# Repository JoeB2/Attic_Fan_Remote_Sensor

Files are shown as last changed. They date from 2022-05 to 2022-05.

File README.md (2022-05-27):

"# attic_fan_remote_sensor" 
Deep Sleep for "deepSleep_us" Value provided by Attic Fan Controller via ESPNOW

On Wake up this unit reads values from a BME280 and its internal VCC and then sends a, 32bytes (JSON string), using ESPNOW
to the Attic Fan Controller of temp/humid/press/vcc.  The Attic Fan Controller updates its struct with the remote values and sends
a JSON string to the Web Page it hosts using WebSockets.  This ESP01 supports ESPNOW only - no WiFi.

The first Remote Sensor iteration of this remote sensor is using two 18650 2300 mah LIPO Cells.

All LEDs on the ESP01 have been removed.
This ESP01 uses 18 ua (18 Micro Amp) in deep sleep and an average of 66 ma for 212 ms during its awake & transmit period.
With a 2 minute deep sleep cycle we could see extended periods of battery life perhaps several years.  (TBD)

If the Attic Fan Controller unit sends an updated sleep_us value this ESP01 power consuption jumps to 385ma during the communication rcx cycle ~45ms. yikes!

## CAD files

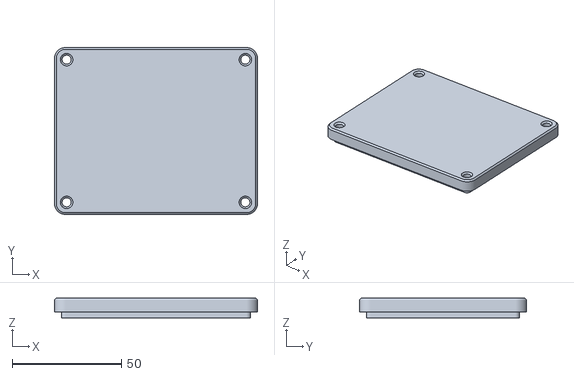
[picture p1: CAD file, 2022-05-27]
box/Lid-AtticFanController.stl
92.8 x 76.3 x 9.05

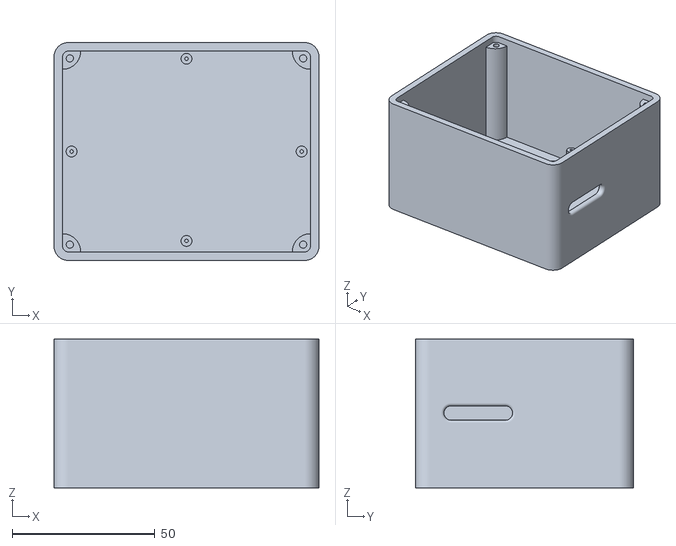
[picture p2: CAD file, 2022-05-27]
box/Box-AtticFanController.stl
92.8 x 76.3 x 52.1

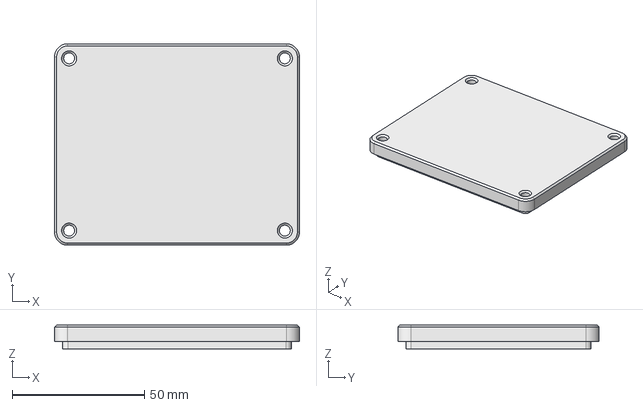
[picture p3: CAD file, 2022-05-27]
box/electonics_box.FCStd
92.8 x 76.3 x 9.05 mm

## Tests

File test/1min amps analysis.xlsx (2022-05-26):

ms | uA
0 | 17.79 | One minute test run. Deep sleep 3 seconds after ESPNOW send of 32 bytes.C45
1 | 17.959 |  | Avgerage ua |  | Period
2 | 17.666 |  | 66042.29058 |  | 212ms
3 | 17.818
4 | 17.728
5 | 17.581
6 | 17.747
7 | 17.763
8 | 17.789
9 | 17.78
10 | 17.783
11 | 17.793
12 | 17.789
13 | 17.79
14 | 17.777
15 | 17.759
16 | 17.786
17 | 17.83
18 | 17.871
19 | 17.838
20 | 17.814
21 | 17.797
22 | 17.805
23 | 17.795
24 | 17.8 |  | avg 2737ua | 6043ms
25 | 17.796
26 | 17.781
27 | 17.751
28 | 17.773
29 | 17.773
30 | 17.764
31 | 17.76
32 | 17.759
33 | 17.755
34 | 17.786
35 | 17.76
36 | 17.76
37 | 17.743
38 | 17.779
39 | 17.802
40 | 17.787
41 | 17.778
42 | 17.761
43 | 17.775
44 | 17.778
45 | 17.743
46 | 17.746
47 | 17.719
48 | 17.784
49 | 17.778
50 | 17.776
51 | 17.767
52 | 17.753
53 | 17.789
54 | 17.795
55 | 17.76
56 | 17.75
57 | 17.741
58 | 17.779
59 | 17.814
60 | 17.774
61 | 17.787
62 | 17.732
63 | 17.787
64 | 17.776
65 | 17.755
66 | 17.78
67 | 17.714
68 | 17.773
69 | 17.796
70 | 17.771
71 | 17.788
72 | 17.734
73 | 17.816
74 | 17.828
75 | 17.837
76 | 17.845
77 | 17.747
78 | 17.806
79 | 17.808
80 | 17.777
81 | 17.764
82 | 17.733
83 | 17.79
84 | 17.799
85 | 17.795
86 | 17.831
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

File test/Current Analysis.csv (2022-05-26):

ms | uA
0 | 18
1 | 18
2 | 18
3 | 18
4 | 18
5 | 18
6 | 18
7 | 18
8 | 18
9 | 18
10 | 18
11 | 18
12 | 18
13 | 18
14 | 18
15 | 18
16 | 18
17 | 18
18 | 18
19 | 18
20 | 18
21 | 18
22 | 18
23 | 18
24 | 18
25 | 18
26 | 18
27 | 18
28 | 18
29 | 18
30 | 18
31 | 18
32 | 18
33 | 18
34 | 18
35 | 18
36 | 18
37 | 18
38 | 18
39 | 18
40 | 18
41 | 18
42 | 18
43 | 18
44 | 18
45 | 18
46 | 18
47 | 18
48 | 18
49 | 18
50 | 18
51 | 18
52 | 18
53 | 18
54 | 18
55 | 18
56 | 18
57 | 18
58 | 18
59 | 18
60 | 18
61 | 18
62 | 18
63 | 18
64 | 18
65 | 18
66 | 18
67 | 18
68 | 18
69 | 18
70 | 18
71 | 18
72 | 18
73 | 18
74 | 18
75 | 18
76 | 18
77 | 18
78 | 18
79 | 18
80 | 18
81 | 18
82 | 18
83 | 18
84 | 18
85 | 18
86 | 18
87 | 18
88 | 18
89 | 18
90 | 18
91 | 18
92 | 18
93 | 18
94 | 18
95 | 18
96 | 18
97 | 18
98 | 18
99 | 18
100 | 18
101 | 18
102 | 18
103 | 18
104 | 18
105 | 18
106 | 18
107 | 18
108 | 18
109 | 18
110 | 18
111 | 18
112 | 18
113 | 18
114 | 18
115 | 18
116 | 18
117 | 18
118 | 18
119 | 18
120 | 18
121 | 18
122 | 18
123 | 18
124 | 18
125 | 18
126 | 18
127 | 18
128 | 18
129 | 18
130 | 18
131 | 18
132 | 18
133 | 18
134 | 18
135 | 18
136 | 18
137 | 18
138 | 18
139 | 18
140 | 18
141 | 18
142 | 18
143 | 18
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

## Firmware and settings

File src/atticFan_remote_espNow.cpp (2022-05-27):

#include <Arduino.h>
/*
      Remote: ESPNOW, DS3231 - Send outside temp & pressure inch of Hg
      1) Remote Sensor:
            Use BME280 sensor, store sensor data in a struct "cond" conditions
            Use espnow: broadcast struct "cond" at sleep_us interval (user adjustable)
            attic esp returns the struct with the sleep_us
            and if the current sleep_us is different we update cond.sleepTime & RTC memory.
            We wait for the response from the "Attic Controller" if after 7 seconds no response:
            this mcu initiates deep sleep

      2) uncomment //#define dbg enables Serial prints at several key locations in the code including the MAC

      3)    esp01 for the remote MCU: requires solder a connection from GPIO16 to RST.
            deepSleep wakes up the MCU by output of signal at GPIO16.
      
      NOTE:
            the attic sensor/controller esp's now_Msg struct must have the exact same definition for the cond struct

  int(4), uint(4), uint32(4), long(4), uLong(4), uLongLong(8), short(2), ushort(2), float(4), double(8)
*/
// extern "C" {
//   #include "user_interface.h" // 
// }

//#define dbg
#ifdef dbg
  u32 ms=millis();
  #define trace Serial.printf("%i %lums, ", __LINE__, millis()-ms);ms=millis(); Serial.flush();
#else
  #define trace ;
#endif

#include <espnow.h>
#include <ESP8266WiFi.h>
#include <EEPROM.h>

#include <Wire.h>  // loaded in TinyBME280.h - should be called: i2c.h or soft_i2c.h  imho

#define WiFiChannel 7

ADC_MODE(ADC_VCC);

//u8 attic_mac[6] = {0xFF,0xFF,0xFF,0xFF,0xFF,0xFF};// MAC: MultiCast"
//u8 attic_mac[6] = {0xE8,0xDB,0x84,0xA9,0x13,0x3A};   // latest ESP01
u8 attic_mac[6] = {0x5C,0xCF,0x7F,0xE1,0x9B,0x8B};   // D1 mini

u32 startMillis=millis();
u16 vcc_correct = -90; // vcc == voltage/1000  : We add correction and divide by 1000
u64 sleep_us = 4000002; // default to 4sec 4us
u8 *p = (u8*)&sleep_us;    // pointer to sleep_us to ease handle by byte

// BME280 Values & Variables
#define SDA 0
#define SCL 2
#define BME280address 0x76

/******  PROTOTYPES  *******/
void OnDataRecv(uint8_t * mac, uint8_t *incomingData, uint8_t len);
void OnDataSent(uint8_t *mac_addr, uint8_t sendStatus);

// BME280
void BME280setup();
void BME280sleep ();
int32_t BME280temperature();
uint32_t BME280pressure();
uint32_t BME280humidity();
uint8_t BME_ID();

typedef struct remote_Data{
  int temp;
  u32 press;
  u32 humid;
  u64 sleep_us = 4000000;
  u16 vcc;

  String toStr(){
    char c[120];
    int n = sprintf(c, "{\"temp\":%i,\"press\":%u,\"humid\",:%u,\"vcc:%hu,\"sleep_us\":%llu}"
      , temp, press, humid, vcc, sleep_us);
    c[n]=0;
    return String(c);
  }
}remote_data_t;
remote_data_t cond;

  void setup() {
    system_update_cpu_freq(SYS_CPU_160MHZ);
    system_deep_sleep_set_option (2);   // No RF cal on wake-up
    // 1: Vdd and TX power, 18 ms // 2: Vdd only, 2 ms // 3: Full cal, 200ms
    system_phy_set_powerup_option (2);
    system_phy_set_rfoption (2);
#ifdef dbg
    Serial.begin(74880);
    Serial.setTimeout(2000);
    while(!Serial){}
#endif
    EEPROM.begin(8);
    for(u8 i=0;i<8;i++)p[i] = EEPROM.read(i);
    EEPROM.end();
    cond.sleep_us = sleep_us;
trace;
    WiFi.setPhyMode(WIFI_PHY_MODE_11B);
    WiFi.setOutputPower(20.5);  // range: 0dbm - 20.5dbm; default 18.5
    WiFi.mode(WIFI_STA);
    WiFi.disconnect();
trace;
    esp_now_init();
    esp_now_register_send_cb(OnDataSent);
    esp_now_register_recv_cb(OnDataRecv);
    esp_now_set_self_role(ESP_NOW_ROLE_COMBO);
    esp_now_add_peer(attic_mac, ESP_NOW_ROLE_COMBO, WiFiChannel, NULL, 0);
trace;
    Wire.begin(SDA, SCL);
    BME280setup();
trace;
    // get the readings once, during startup (here!)
    cond.temp  = BME280temperature(); // .018 x temp +32  : done at index.html
    cond.press = BME280pressure();    // p x 0.00029529983071445 = in Hg  done int index.html
    cond.humid = BME280humidity();    // humidity / 100 done in index.html
    BME280sleep();
    cond.vcc   = ESP.getVcc() + vcc_correct; // below 3.0volts shutdown; battery needs to be charged
trace;
    esp_now_send(attic_mac, (u8*)&cond, sizeof(cond));
    delay(45); // takes 45-51ms to get here. timeout after ~100ms -> goto sleep
#ifdef dbg
    Serial.printf("\n%i %s %lu\n", __LINE__, __FUNCTION__, millis());Serial.flush();
    Serial.printf("%i %s %lums, ", __LINE__, cond.toStr().c_str(), millis());Serial.flush();
#endif
     ESP.deepSleepInstant(sleep_us, WAKE_RFCAL);
  }
  void loop(){}
  void OnDataRecv(uint8_t * mac, uint8_t *incomingData, uint8_t len){
trace;
    for(u8 i=0;i<len;i++)p[i] = incomingData[i];
trace;
    if(cond.sleep_us ^ sleep_us && sleep_us < ESP.deepSleepMax()){
trace;
      EEPROM.begin(8);
trace;
      for(u8 i=0;i<8;i++)EEPROM.write(i, p[i]);
trace;
      EEPROM.commit();
trace;
      EEPROM.end();
trace;
    }
trace;
    if(cond.vcc<(u16)3000){ESP.deepSleepInstant(0, WAKE_RF_DISABLED);}
#ifdef dbg
    Serial.printf("%i %s %lu max: %llu, ", __LINE__, __FUNCTION__, millis(), ESP.deepSleepMax());Serial.flush();
#endif
    ESP.deepSleepInstant(sleep_us, WAKE_NO_RFCAL); // Pin 16 must attach to rst for wakeup
  }
  void OnDataSent(uint8_t *mac_addr, uint8_t sendStatus){}
/* TinyBME280 Library v2

   David Johnson-Davies - www.technoblogy.com - 22nd June 2019
   
   CC BY 4.0
   Licensed under a Creative Commons Attribution 4.0 International license: 
   http://creativecommons.org/licenses/by/4.0/
*/
int16_t T[4], P[10], H[7]; // DON'T TOUCH -> TinyBME use
int32_t BME280t_fine;      // DON'T TOUCH -> TinyBME use

int16_t read16 () {
  uint8_t lo, hi;
  lo = Wire.read(); hi = Wire.read();
  return hi<<8 | lo;
}
int32_t read32 () {
  uint8_t msb, lsb, xlsb;
  msb = Wire.read(); lsb = Wire.read(); xlsb = Wire.read();
  return (uint32_t)msb<<12 | (uint32_t)lsb<<4 | (xlsb>>4 & 0x0F);
}
uint8_t BME_ID(){
  delay(2);
  // Set the mode to Normal, no upsampling
  Wire.beginTransmission(BME280address);
  Wire.write(0xD0);
  Wire.endTransmission();
  Wire.requestFrom(BME280address, 1);
  return((uint8_t)Wire.read());
}
// Must be called once at start
void BME280setup () {
  delay(2);
  // Set the mode to Normal, no upsampling
  Wire.beginTransmission(BME280address);
  Wire.write(0xF2);        // ctrl_hum
  Wire.write(0b00000001);  // Oversample H: 1x
  Wire.write(0xF4);        // ctrl_meas
  Wire.write(0b00100101);  // Oversample T: 1x; P: 1x : Force Mode 

  Wire.write(0xF5);         // config
  Wire.write(0b10100000);  // 101 inactive 1000ms, IIR 125ms, I2C mode

  // Read the chip calibrations.
  Wire.write(0x88);
  Wire.endTransmission();
  Wire.requestFrom(BME280address, 26);
  for (int i=1; i<=3; i++) T[i] = read16();     // Temperature
  for (int i=1; i<=9; i++) P[i] = read16();     // Pressure
  Wire.read();  // Skip 0xA0
  H[1] = (uint8_t)Wire.read();                  // Humidity
  //
  Wire.beginTransmission(BME280address);
  Wire.write(0xE1);
  Wire.endTransmission();
  Wire.requestFrom(BME280address, 7);
  H[2] = read16();
  H[3] = (uint8_t)Wire.read();
  uint8_t e4 = Wire.read(); uint8_t e5 = Wire.read();
  H[4] = ((int16_t)((e4 << 4) + (e5 & 0x0F)));
  H[5] = ((int16_t)((Wire.read() << 4) + ((e5 >> 4) & 0x0F)));
  H[6] = ((int8_t)Wire.read()); // 0xE7
  // Read the temperature to set BME280t_fine
  BME280temperature();
}
// Can be called if sensor can sleep to save energy
void BME280sleep () {
  delay(2);
  // Set the mode to Normal, no upsampling
  Wire.beginTransmission(BME280address);
  Wire.write(0xF4);                             // ctrl_meas
  Wire.write(0b00000000);                       // what can be better than sleep?!
  Wire.endTransmission();
}
// Returns temperature in DegC, resolution is 0.01 DegC
// Output value of “5123” equals 51.23 DegC
int32_t BME280temperature () {
  Wire.beginTransmission(BME280address);
  Wire.write(0xFA);
  Wire.endTransmission();
  Wire.requestFrom(BME280address, 3);
  int32_t adc = read32();
  // Compensate
  int32_t var1, var2, t; 
  var1 = ((((adc>>3) - ((int32_t)((uint16_t)T[1])<<1))) * ((int32_t)T[2])) >> 11;
  var2 = ((((adc>>4) - ((int32_t)((uint16_t)T[1]))) * ((adc>>4) - ((int32_t)((uint16_t)T[1])))) >> 12);
  var2 = (var2 * ((int32_t)T[3])) >> 14;
  BME280t_fine = var1 + var2;
  return (BME280t_fine*5+128)>>8;
}
// Returns pressure in Pa as unsigned 32 bit integer
// Output value of “96386” equals 96386 Pa = 963.86 hPa
uint32_t BME280pressure () {
  Wire.beginTransmission(BME280address);
  Wire.write(0xF7);
  Wire.endTransmission();
  Wire.requestFrom(BME280address, 3);
  int32_t adc = read32();
  // Compensate
  int32_t var1, var2;
  uint32_t p;
  var1 = (((int32_t)BME280t_fine)>>1) - (int32_t)64000;
  var2 = (((var1>>2) * (var1>>2)) >> 11 ) * ((int32_t)P[6]);
  var2 = var2 + ((var1*((int32_t)P[5]))<<1);
  var2 = (var2>>2) + (((int32_t)P[4])<<16);
  var1 = (((P[3] * (((var1>>2) * (var1>>2)) >> 13 )) >> 3) + ((((int32_t)P[2]) * var1)>>1))>>18;
  var1 = ((((32768+var1))*((int32_t)((uint16_t)P[1])))>>15);
  if (var1 == 0) return 0;
  p = (((uint32_t)(((int32_t)1048576) - adc) - (var2>>12)))*3125;
  if (p < 0x80000000) p = (p << 1) / ((uint32_t)var1);
  else p = (p / (uint32_t)var1) * 2;
  var1 = (((int32_t)P[9]) * ((int32_t)(((p>>3) * (p>>3))>>13)))>>12;
  var2 = (((int32_t)(p>>2)) * ((int32_t)P[8]))>>13;
  p = (uint32_t)((int32_t)p + ((var1 + var2 + P[7]) >> 4));
  return p;
}
// Humidity in %RH, resolution is 0.01%RH
// Output value of “4653” represents 46.53 %RH
uint32_t BME280humidity () {
  Wire.beginTransmission(BME280address);
  Wire.write(0xFD);
  Wire.endTransmission();
  Wire.requestFrom(BME280address, 2);
  uint8_t hi = Wire.read(); uint8_t lo = Wire.read();
  int32_t adc = (uint16_t)(hi<<8 | lo);
  // Compensate
  int32_t var1; 
  var1 = (BME280t_fine - ((int32_t)76800));
  var1 = (((((adc << 14) - (((int32_t)H[4]) << 20) - (((int32_t)H[5]) * var1)) +
  ((int32_t)16384)) >> 15) * (((((((var1 * ((int32_t)H[6])) >> 10) * (((var1 *
  ((int32_t)H[3])) >> 11) + ((int32_t)32768))) >> 10) + ((int32_t)2097152)) *
  ((int32_t)H[2]) + 8192) >> 14));
  var1 = (var1 - (((((var1 >> 15) * (var1 >> 15)) >> 7) * ((int32_t)H[1])) >> 4));
  var1 = (var1 < 0 ? 0 : var1);
  var1 = (var1 > 419430400 ? 419430400 : var1);
  return (uint32_t)((var1>>12)*25)>>8;
}

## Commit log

2022-05-26 Completed the Project, working in production
    [1min amps analysis.xlsx, Current Analysis.csv]
2022-05-27 v1 completed
    [Box-AtticFanController.stl, Lid-AtticFanController.stl, electonics_box.FCStd]
